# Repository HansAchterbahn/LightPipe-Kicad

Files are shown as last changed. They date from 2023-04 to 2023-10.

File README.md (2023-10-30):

# LightPipe - Main PCB (Kicad)

LightPipes are colorful lighting pipes that can be combined to create complex and interesting geometries. The LightPipe project is based on the easily addressable APA102 RGB LEDs. Each LED in a LightPipe geometry can be addressed individually.

The LightPipe project uses the PCB in this project in a slightly modified form as input and output PCB. On the input side, it simply accepts data from a 3.5 jack and power from an XT30 connector. On the output side, the data is output to the next LightPipe via the same jack and power is supplied via the same XT30 connector.

An additional 3.5 female connector is used to tunnel the data from the output PCB back to the input PCB. With this arrangement it is possible to realize a complete tree structure and therefore to create arbitrary geometries.

In this repository you will find the schematics and board layouts created in KiCad. You will also find a 3D model of the PCB.

*Fork me and have fun!*

LightPipe first Prototyep @ Neotopia Hackspace in Göttingen
**LightPipe - First Prototyep @ Neotopia Hackspace in Göttingen**

## PCB 3D view

Animated 3D STL model: [kibot/3d/model](kibot/3d/model)

__Top view__

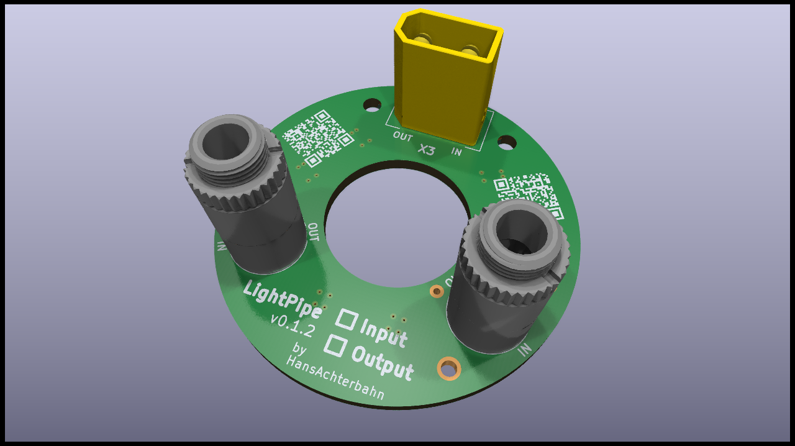
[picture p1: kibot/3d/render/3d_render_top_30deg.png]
Top view 30°


__Bottom view__

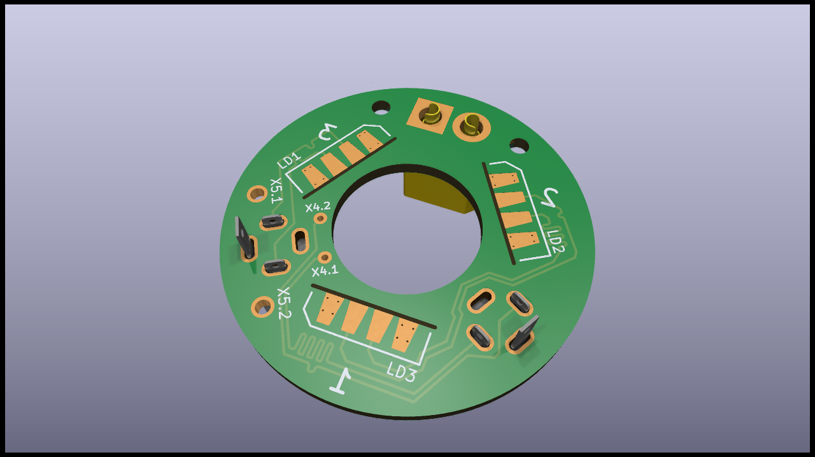
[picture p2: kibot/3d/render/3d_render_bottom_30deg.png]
Bottom view


## Schematic

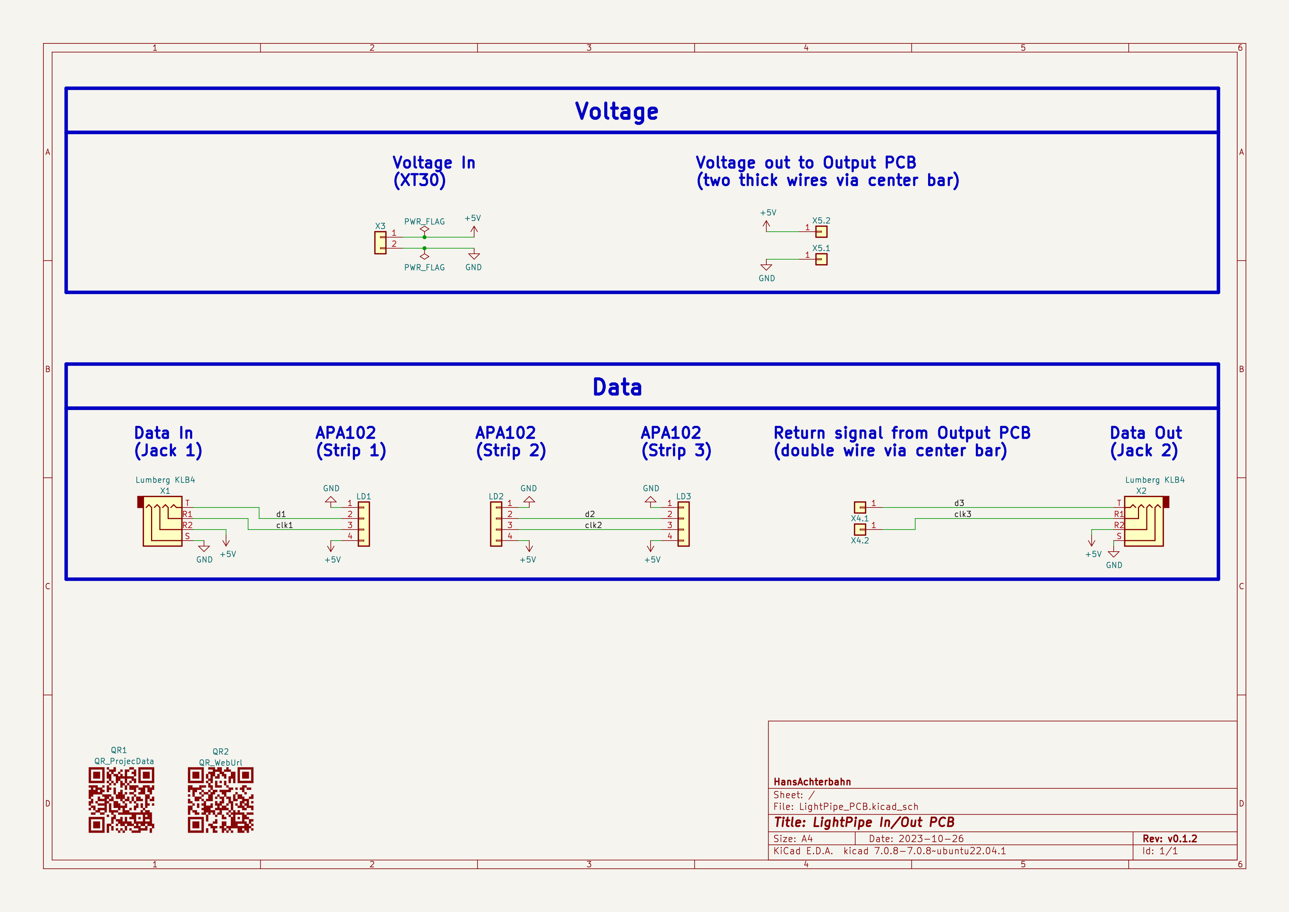
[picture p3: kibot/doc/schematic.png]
Schematic view


## Board

__Top view__

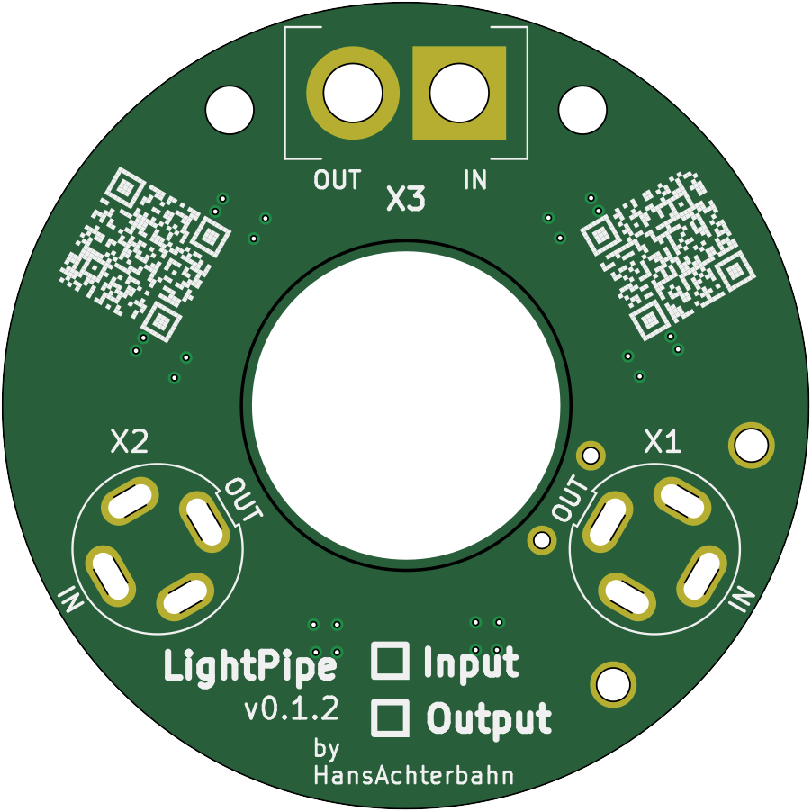
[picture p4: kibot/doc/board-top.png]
Top view


__Bottom view__

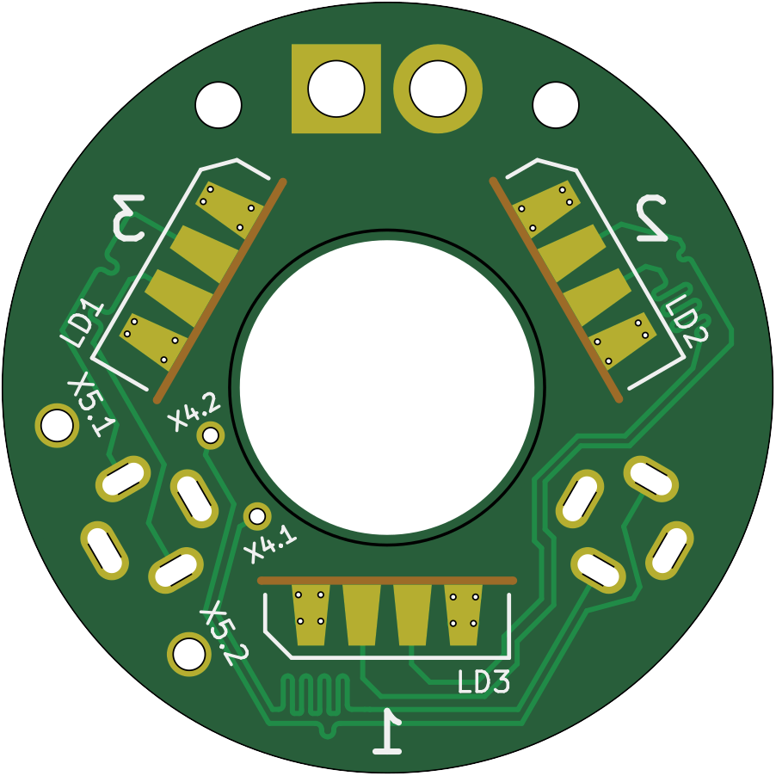
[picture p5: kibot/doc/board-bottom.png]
Bottom view


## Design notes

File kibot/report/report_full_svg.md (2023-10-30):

# PCB

Board size: 38.0x38.0 mm (1.5x1.5 inches)

- This is the size of the rectangle that contains the board
- Thickness: 1.6 mm (63 mils)
- Material: FR4
- Finish: None
- Layers: 4
- Copper thickness: 35 µm

Solder mask: TOP / BOTTOM

- Color: Green

Silk screen: TOP / BOTTOM

- Color: White

Stackup:

| Name | Type | Color | Thickness | Material | Epsilon_r | Loss tangent |
|---|---|---|---|---|---|---|
| F.SilkS | Top Silk Screen | | | | | |
| F.Paste | Top Solder Paste | | | | | |
| F.Mask | Top Solder Mask | | 10 | | | |
| F.Cu | copper | | 35 | | | |
| dielectric 1 | core | | 695 | FR4 | 4.5 | 0.020 |
| In1.Cu | copper | | 35 | | | |
| dielectric 2 | prepreg | | 50 | FR4 | 4.5 | 0.020 |
| In2.Cu | copper | | 35 | | | |
| dielectric 3 | core | | 695 | FR4 | 4.5 | 0.020 |
| B.Cu | copper | | 35 | | | |
| B.Mask | Bottom Solder Mask | | 10 | | | |
| B.Paste | Bottom Solder Paste  | | | | | |
| B.SilkS | Bottom Silk Screen | | | | | |

# Important sizes

Clearance: 0.2 mm (8 mils)

Track width: 0.25 mm (10 mils)

- By design rules: 0.2 mm (8 mils)

Drill: 0.3 mm (12 mils)

- Vias: 0.3 mm (12 mils) [Design: 0.3 mm (12 mils)]
- Pads: 0.8 mm (31 mils)
- The above values are real drill sizes, they add 0.1 mm (4 mils) to plated holes (PTH)

Via: 0.6/0.2 mm (24/8 mils)

- By design rules: 0.4/0.2 mm (16/8 mils)
- Micro via: yes [0.2/0.1 mm (8/4 mils)]
- Buried/blind via: yes
- Total: 24 (thru: 24 buried/blind: 0 micro: 0)

Outer Annular Ring: 0.15 mm (6 mils)

- By design rules: 0.15 mm (6 mils)

Eurocircuits class: 4D
- Using min drill 0.3 mm for an OAR of 0.15 mm

# General stats

Components count: (SMD/THT)

- Top: 0/3 (THT)
- Bottom: 3/2 (SMD + THT)

Defined tracks:

- 0.5 mm (20 mils)
- 0.75 mm (30 mils)
- 1.0 mm (39 mils)
- 1.5 mm (59 mils)
- 2.0 mm (79 mils)

Used tracks:

- 0.25 mm (10 mils) (114) defined: no

Defined vias:

- 0.6/0.2 mm (24/8 mils)

Used vias:

- 0.6/0.2 mm (24/8 mils) (Count: 24, Aspect: 2.7 A) defined: yes

Holes (excluding vias):

- 0.7 mm (28 mils) (2)
- 1.5 mm (59 mils) (2)
- 2.2 mm (87 mils) (2)
- 2.7 mm (106 mils) (2)

Oval holes:

- 1.0x2.2 mm (39x87 mils) (4)
- 1.0x2.4 mm (39x94 mils) (4)

Drill tools (including vias and computing adjusts and rounding):

- 0.3 mm (12 mils) (24)
- 0.8 mm (31 mils) (2)
- 1.1 mm (43 mils) (8)
- 1.6 mm (63 mils) (2)
- 2.2 mm (87 mils) (2)
- 2.8 mm (110 mils) (2)

# PCB Layers

PCB Top

PCB In1

PCB In2

PCB Bottom

PCB Assembly Top

PCB Assembly Bottom

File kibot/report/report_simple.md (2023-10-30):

PCB Specifications:
Size:

- 38.0x38.0 mm

Class: 4D

Track width: >= 0.25 mm

Insulation distance: >= 0.2 mm

Minimum drill size: >= 0.3 mm (finished metalized hole: 0.2 mm)

Minimum slot width: >= 1.0 mm

Ring collar: >= 0.15 mm

Stackup:

| Name | Type | Color | Thickness | Material | Epsilon_r | Loss tangent |
|---|---|---|---|---|---|---|
| F.SilkS | Top Silk Screen | | | | | |
| F.Paste | Top Solder Paste | | | | | |
| F.Mask | Top Solder Mask | | 10 | | | |
| F.Cu | copper | | 35 | | | |
| dielectric 1 | core | | 695 | FR4 | 4.5 | 0.020 |
| In1.Cu | copper | | 35 | | | |
| dielectric 2 | prepreg | | 50 | FR4 | 4.5 | 0.020 |
| In2.Cu | copper | | 35 | | | |
| dielectric 3 | core | | 695 | FR4 | 4.5 | 0.020 |
| B.Cu | copper | | 35 | | | |
| B.Mask | Bottom Solder Mask | | 10 | | | |
| B.Paste | Bottom Solder Paste  | | | | | |
| B.SilkS | Bottom Silk Screen | | | | | |

Materials:

- FR4, 1.6 mm
- None
- 4 layers
- 35 µm copper thickness

Solder mask:

- TOP / BOTTOM
- Green

Marking:

- TOP / BOTTOM screen printing
- Silk: White

Other markings:

- ROHS / UL / Date - Yes if available

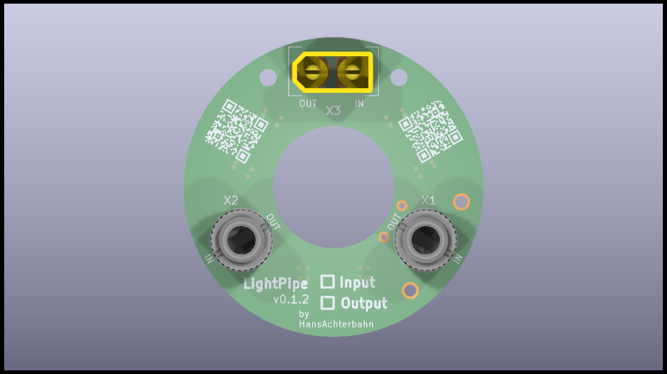
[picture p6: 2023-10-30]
kibot/3d/render/3d_render_top.png

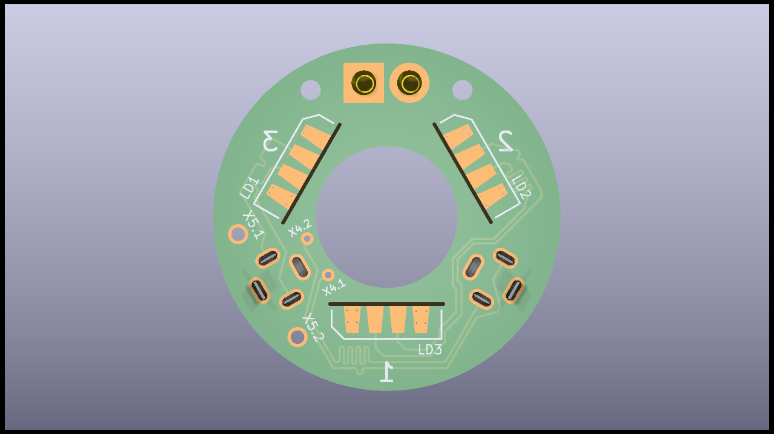
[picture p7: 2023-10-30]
kibot/3d/render/3d_render_bottom.png

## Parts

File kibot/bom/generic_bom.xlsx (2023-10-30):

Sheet: BoM
 |  | KiBot Bill of Materials
 |  | Schematic: | LightPipe_PCB | Component Groups: | 2
 |  | Variant: | default | Component Count: | 3 (0 SMD/ 3 THT)
 |  | Revision: | v0.1.2 | Fitted Components: | 3 (0 SMD/ 3 THT)
 |  | Date: | 2023-10-26 | Number of PCBs: | 1
 |  | KiCad Version: | 7.0.8-7.0.8~ubuntu22.04.1 | Total Components: | 3
Row | Description | Part | References | Value | Footprint | Quantity Per PCB | Status | Datasheet | MF | MFN | LCSC# | MF1 | MFN1 | qr_version | qr_size | qr_ecc | qr_mask | qr_text
1 | Audio Jack, 4 Poles (TRRS) | AudioJack4 | X1 X2 | Lumberg KLB4 | Lumberg-KLB-4-Jack-3_5-180deg-turnable | 2 |  | https://downloads.lumberg.com/datenblaetter/en/klb4.pdf | Lumberg | KLB4 |  | HUXUAN | PJ392
2 | Generic connector, single row, 01x02, script generated (kicad-library-utils/schlib/autogen/connector/) | Conn_01x02 | X3 | XT30 | XT30 | 1 |  | https://datasheet.lcsc.com/lcsc/2207151430_Changzhou-Amass-Elec-XT30UPB30-F-G--_C108769.pdf | Changzhou Amass Elec | XT30UPB30-F.G.* | C108769

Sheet: Colors
KiCad Fields (default)
Generated Fields
User Fields
Empty Fields

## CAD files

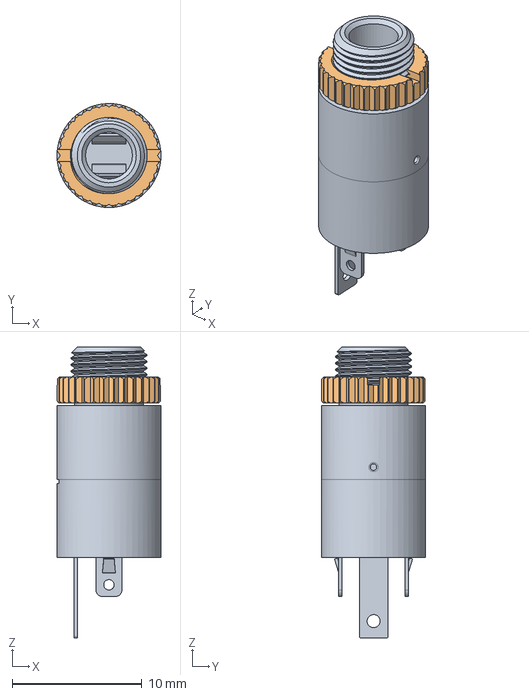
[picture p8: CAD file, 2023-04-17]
3D-Modells/Lumberg_KLB_4.stp
8.00 x 8.00 x 22.4 mm

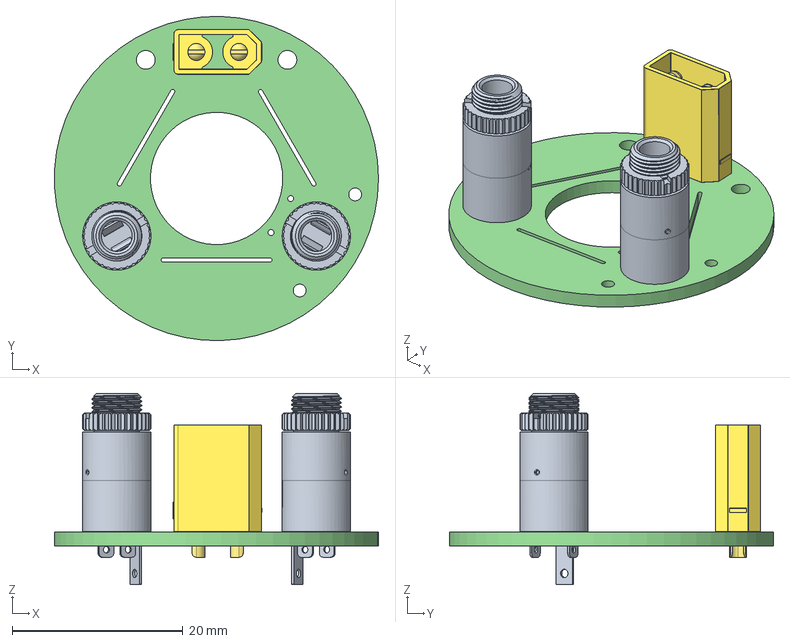
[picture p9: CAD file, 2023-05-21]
kibot/3d/model/LightPipe_PCB-3D-Model.step
38.0 x 38.0 x 22.4 mm
LightPipe_PCB PCB

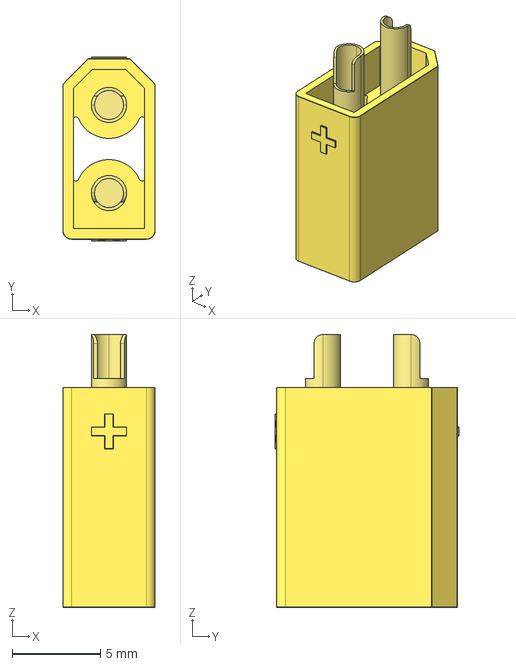
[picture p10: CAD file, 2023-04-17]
3D-Modells/XT30-male.stp
5.25 x 10.4 x 15.5 mm

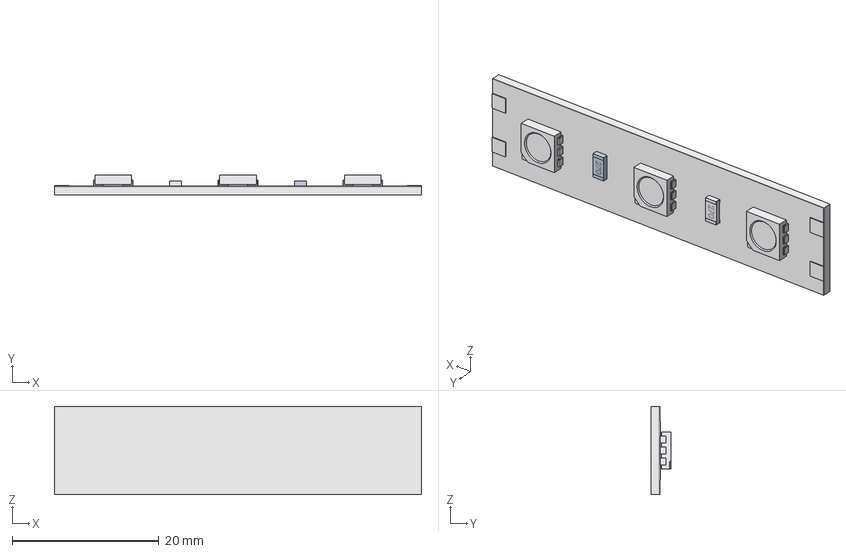
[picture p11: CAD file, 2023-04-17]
3D-Modells/LED-Strip-5050-2-Pole.stp
50.0 x 2.70 x 12.0 mm
stripPad
led5052 x 3
Resistor1206
Resistor1207

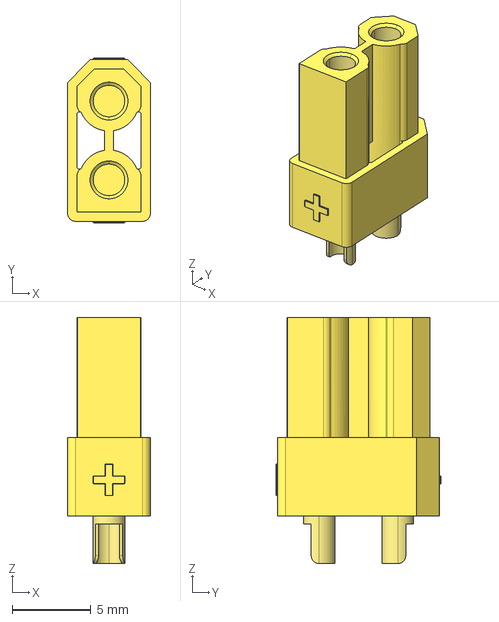
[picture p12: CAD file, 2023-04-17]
3D-Modells/XT30-female.stp
5.25 x 10.4 x 15.6 mm

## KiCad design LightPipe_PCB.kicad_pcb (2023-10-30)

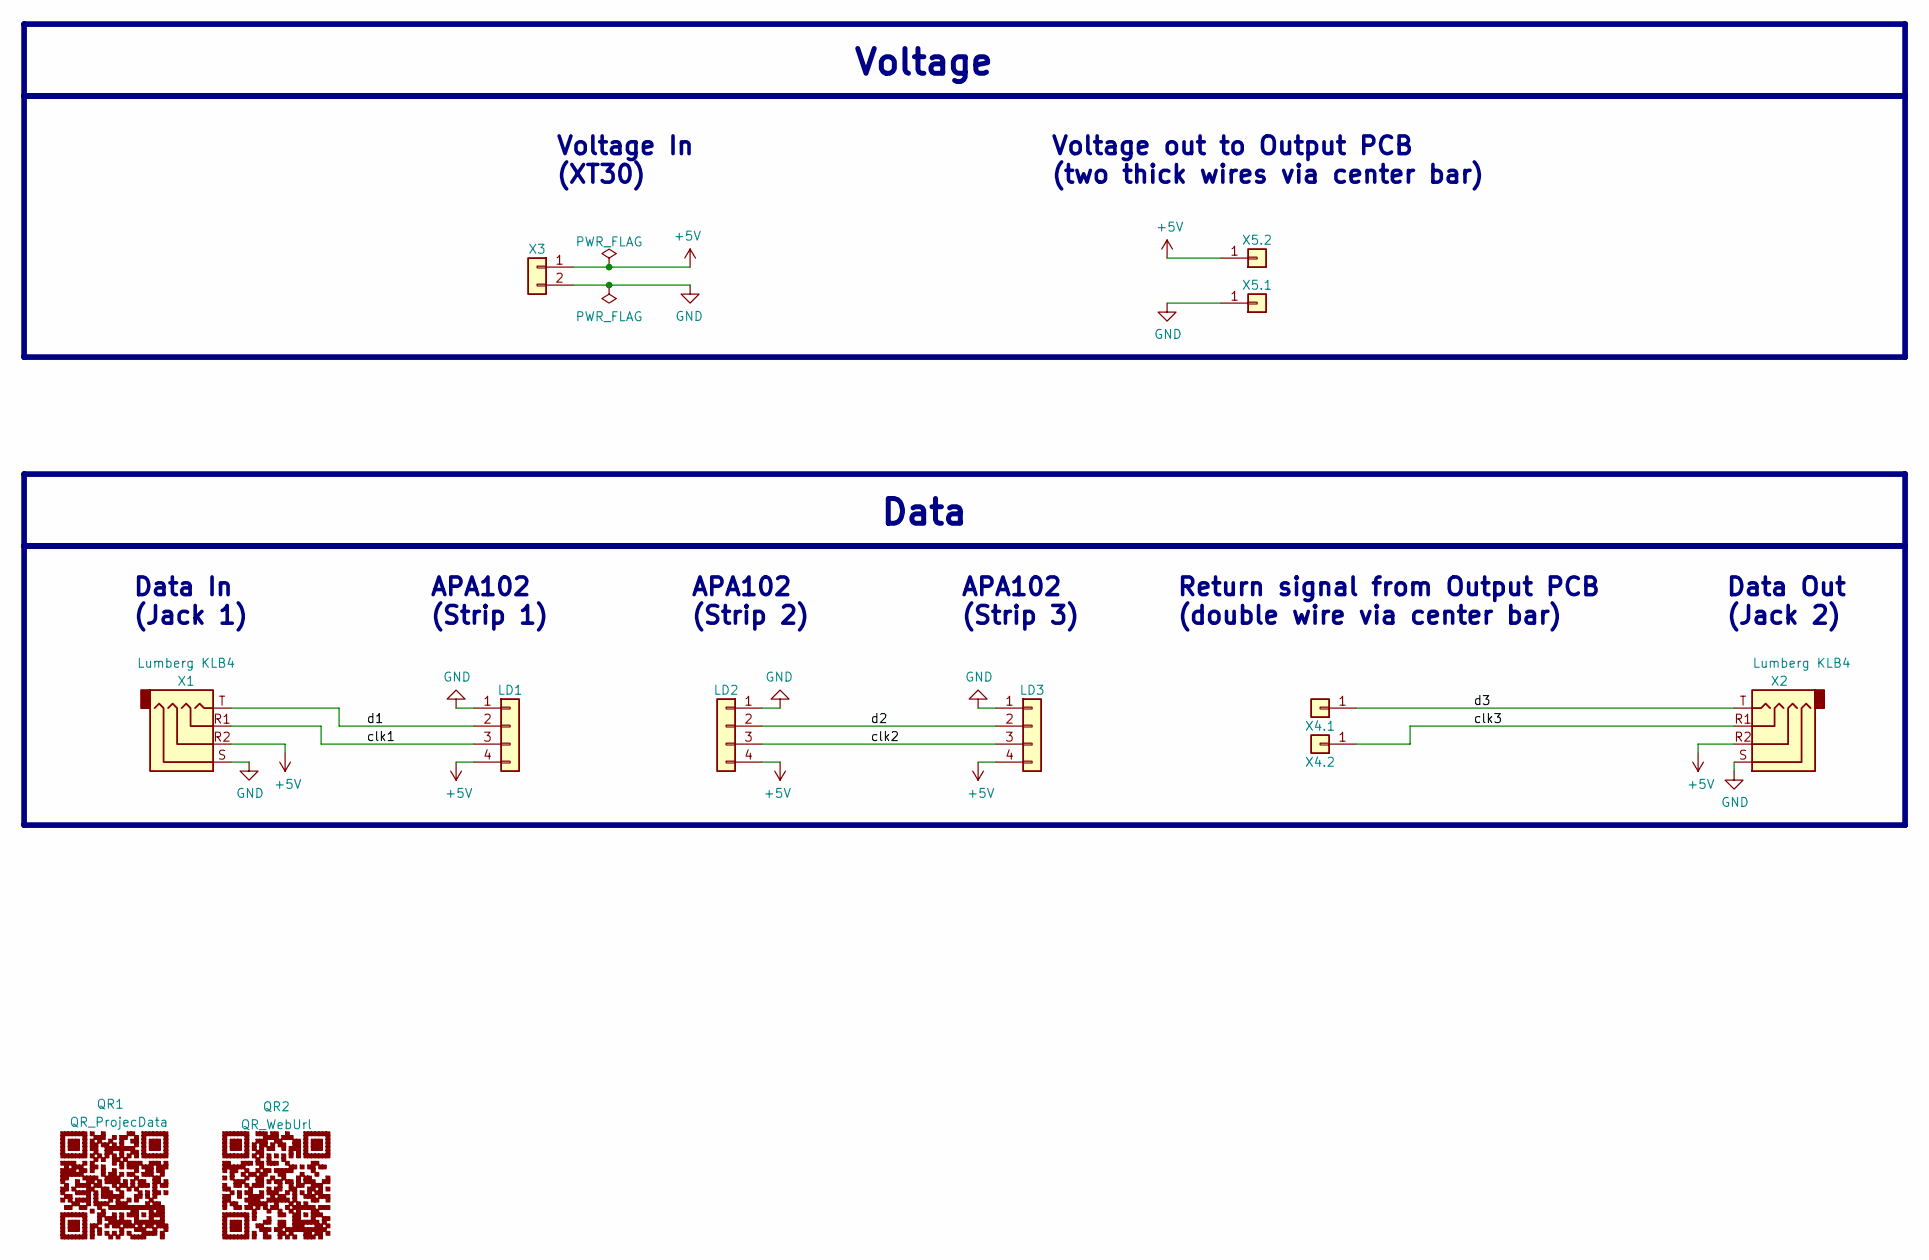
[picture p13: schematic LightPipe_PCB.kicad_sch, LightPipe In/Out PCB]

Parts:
LD1, LD3: APA102; APA102-Strip-Output
LD2: APA102; APA102-Strip-Input
QR1: QR_ProjecData
QR2: QR_WebUrl
X1, X2: Lumberg KLB4; Lumberg-KLB-4-Jack-3_5-180deg-turnable
X3: XT30; LCSC# C108769
X4.1, X4.2: Cable-0.7mm; Solder-Pad-THT-0.7mm
X5.1, X5.2: Cable-1.5mm; Solder-Pad-THT-1.5mm

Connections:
+5V: LD1.4, LD2.4, LD3.4, X1.R2, X2.R2, X3.1, X5.2.1
/clk1: LD1.3, X1.R1
/clk2: LD2.3, LD3.3
/clk3: X2.R1, X4.2.1
/d1: LD1.2, X1.T
/d2: LD2.2, LD3.2
/d3: X2.T, X4.1.1
GND: LD1.1, LD2.1, LD3.1, X1.S, X2.S, X3.2, X5.1.1

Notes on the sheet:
Data Out (Jack 2)
APA102 (Strip 1)
APA102 (Strip 3)
Data
Return signal from Output PCB (double wire via center bar)
Data In (Jack 1)
APA102 (Strip 2)
Voltage out to Output PCB (two thick wires via center bar)
Voltage
Voltage In (XT30)

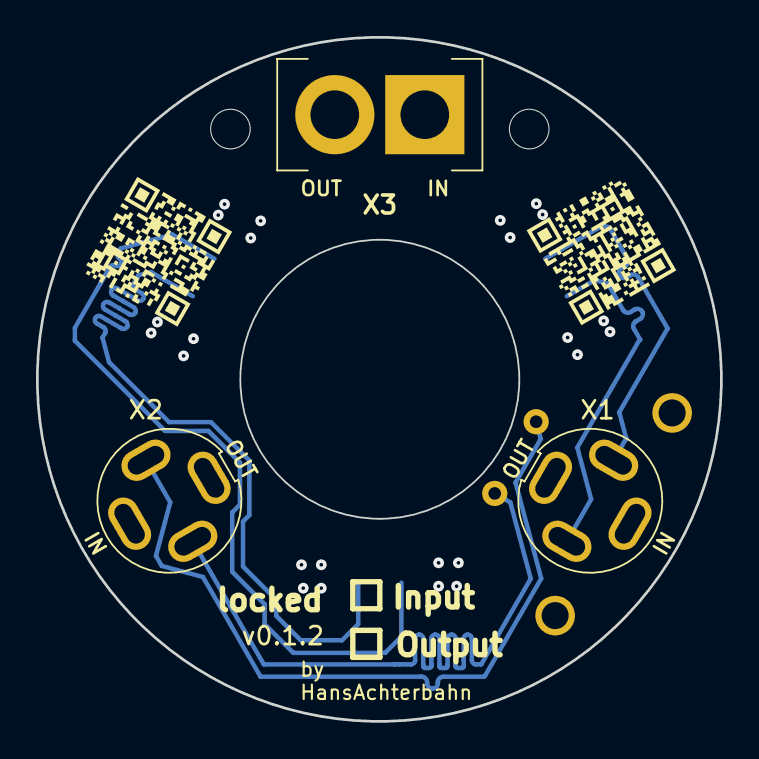
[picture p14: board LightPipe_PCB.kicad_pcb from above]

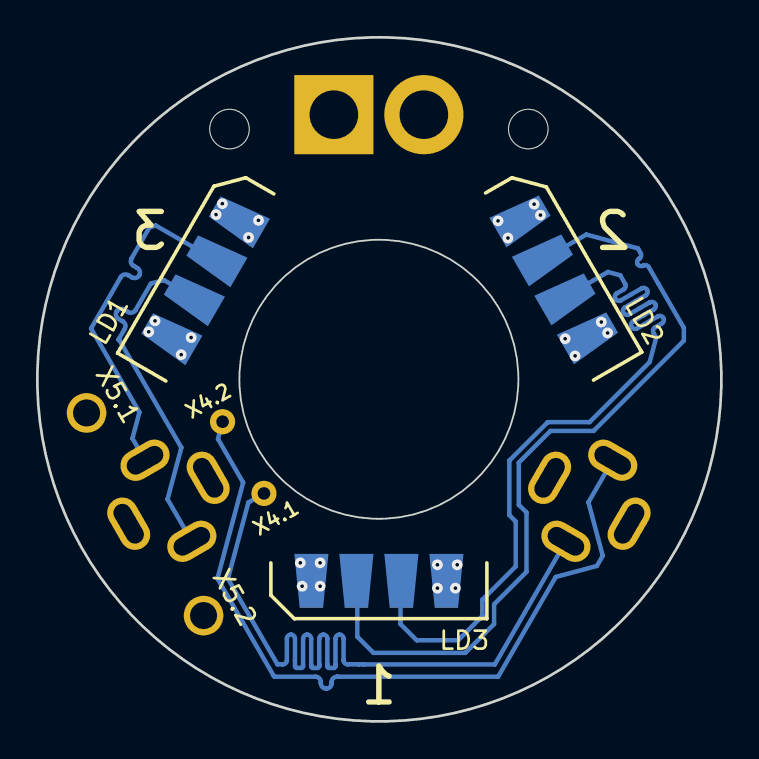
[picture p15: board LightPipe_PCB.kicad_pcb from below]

Board: 4 copper layers, 38.0 x 38.0 mm, 14 parts (7 on the bottom side), 8 nets.

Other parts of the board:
M1, M2: 2.2mm_M2; MountingHole_2.2mm_M2

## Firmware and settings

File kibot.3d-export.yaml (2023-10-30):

# This is a working example.
# For a more complete reference use `--example`
kibot:
  version: 1

preflight:
  # [boolean=false] Zones are filled before doing any operation involving PCB layers
  check_zone_fills: true
  # [boolean=false] Option for `run_drc`. Ignores the unconnected nets. Useful if you didn't finish the routing
  ignore_unconnected: false
  # [boolean=false] Runs the DRC (Distance Rules Check). To ensure we have a valid PCB
  run_drc: false
  # [boolean=false] Runs the ERC (Electrical Rules Check). To ensure the schematic is electrically correct
  run_erc: false
  # [boolean=false] Update the XML version of the BoM (Bill of Materials).
       # To ensure our generated BoM is up to date.
       # Note that this isn't needed when using the internal BoM generator (`bom`)
  update_xml: false

global:
  filters:
  - number: 1007
  - number: 1015
  - number: 58

filters:
- name: only_jlc_parts
  comment: Only parts with JLC (LCSC) code
  type: generic
  include_only:
  - column: LCSC#
    regex: ^C\d+

variants:
- name: place_holder
  comment: Just a place holder for pre_transform filters
  type: kicost
  pre_transform:
  - _kicost_rename
  - _rot_footprint

outputs:

################################################################################
# PCB Draw (2D Board Renderer)
################################################################################
- name: basic_pcbdraw_svg_jlcpcb_green_enig_top
  comment: PCB 2D render in SVG format, using jlcpcb-green-enig style
  type: pcbdraw
  dir: kibot/doc
  options:
    style: jlcpcb-green-enig
    format: png
    dpi: 600
    output: 'board-top.%x'
- name: basic_pcbdraw_svg_jlcpcb_green_enig_bottom
  comment: PCB 2D render in SVG format, using jlcpcb-green-enig style
  type: pcbdraw
  dir: kibot/doc
  options:
    style: jlcpcb-green-enig
    format: png
    dpi: 600
    bottom: true
    output: 'board-bottom.%x'
    show_components: 'all'


################################################################################
# 3D Model
################################################################################

# # 3D STEP model creation
# - name: basic_step
#   comment: 3D model in STEP format
#   type: step
#   dir: kibot/3d/model
#   options:
#     output: '%f-3D-Model.%x'

# 3D Renderer
- name: basic_render_3d_top
  comment: 3D view from top
  type: render_3d
  dir: kibot/3d/render
  options:
    output: '3d_render_top.%x'
    ray_tracing: true
    orthographic: true
    zoom: 3
    height:  720 #1440
    width:  1280 #2560
- name: basic_render_3d_top_30deg
  comment: 3D view from top 30 degrees
  type: render_3d
  dir: kibot/3d/render
  output_id: 30deg
  options:
    output: '3d_render_top_30deg.%x'
    ray_tracing: true
    rotate_x: 3
    rotate_z: 2
    zoom: 3
    height:  720 #1440
    width:  1280 #2560
- name: basic_render_3d_bottom
  comment: 3D view from bottom
  type: render_3d
  dir: kibot/3d/render
  options:
    output: '3d_render_bottom.%x'
    ray_tracing: true
    orthographic: true
    view: bottom
    zoom: 3
    height:  720 #1440
    width:  1280 #2560
- name: basic_render_3d_bottom_30deg
  comment: 3D view from bottom 30 degrees
  type: render_3d
  dir: kibot/3d/render
  output_id: 30deg
  options:
    output: '3d_render_bottom_30deg.%x'
    ray_tracing: true
    rotate_x: 3
    rotate_z: -2
    view: bottom
    zoom: 3
    height:  720 #1440
    width:  1280 #2560

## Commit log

2020-10-24 First schematic draft
    [LightPipe.kicad_pcb, LightPipe.sch]
2021-08-06 first PCB draft
    [LED-Strip-5050-2-Pole.stp, LightPipe.kicad_pcb, Lumberg_KLB_4.stp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]
2023-01-01 PCB looks quite good
    [LightPipe.kicad_pcb, LightPipe_Out_PCB.kicad_pcb, LightPipe_Out_PCB.kicad_sch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]
2023-01-01 changed position of some silkscreen names
    [LightPipe_Out_PCB.kicad_pcb]
2023-01-12 [PCB] New Design features to use the PCB as In- and Out-PCB
    [LightPipe_Out_PCB.kicad_pcb, LightPipe_Out_PCB.kicad_sch]
2023-01-16 Changed designators from J? to X? and LD? | Improved Footprints
    [LightPipe_Out_PCB.kicad_pcb, LightPipe_Out_PCB.kicad_sch]
2023-01-28 [PCB] Improved footprints | optimized footprint locations | optimized wires
    [LightPipe_Out_PCB.kicad_pcb, LightPipe_Out_PCB.kicad_sch]
2023-01-28 [clean] removed old schematic file type
    [LightPipe_Out_PCB.sch]
2023-01-28 [doc] Create KiBot export and a basic documentation in README.md
    [LightPipe_Out_PCB-3D-Model.step, LightPipe_Out_PCB.kicad_pcb, generic_bom.xlsx]
2023-01-28 [QR] Added QR-Code to schematic | defined QR-Code on Board to be not on schematic
    [LightPipe_Out_PCB.kicad_pcb, LightPipe_Out_PCB.kicad_sch]
2023-04-07 [pcb] Optimized X1 and X2 positon
    [LightPipe_Out_PCB.kicad_pcb, LightPipe_Out_PCB.kicad_sch]
2023-04-07 [clean] Renamed project to have a generic name for input and output pcb
    [LightPipe_PCB.kicad_pcb, LightPipe_PCB.kicad_sch]
2023-04-07 [clean] Optimized schematic to be easy readable as input PCB | changed 3D bodys in PCB to Input PCB positions | update date, company, project name and QR-code in schematic and board
    [LightPipe_PCB.kicad_pcb, LightPipe_PCB.kicad_sch]
2023-04-10 [mechanical constrains] increased inner board diameter | reduced outer board diameter | added PCB name, version and creator to silkscreen
    [LightPipe_PCB.kicad_pcb]
2023-04-10 [kibot] Executed Kibot script to generate documentation, manufacturing and assembly data
    [LightPipe_PCB-3D-Model.step, generic_bom.xlsx]
2023-04-12 [DRC] Solved DRC errors
    [LightPipe_PCB.kicad_pcb, LightPipe_PCB.kicad_sch]
2023-04-12 [kibot] Improved Settings: Inner layer in Gerber export were missing | reduced image size of 3d rendered PCB
    [LightPipe_Out_PCB-3D-Model.step, LightPipe_PCB-3D-Model.step, generic_bom.xlsx]
2023-04-28 [clean] improved schematic and pcb to be easier to read in Input-Mode
    [LightPipe_PCB.kicad_pcb, LightPipe_PCB.kicad_sch]
2023-05-04 [clean] improved schematic and pcb to be easier to read in Input-Mode 2
    [LightPipe_PCB.kicad_pcb, LightPipe_PCB.kicad_sch]
2023-05-06 [PCB] Update footprint APA102 → Reduced the size of the slit in the PCB
    [LightPipe_PCB.kicad_pcb]
2023-05-21 [PCB] Fixed Fab layers | added attributes to components
    [LightPipe_PCB.kicad_pcb, LightPipe_PCB.kicad_sch]
2023-05-21 [Kibot] Splited basic-export in to basic-export and 3d-export → better performance for basic-export
2023-05-21 [Kibot] Run job 'basic-export' and '3d-export'
    [LightPipe_PCB-3D-Model.step, generic_bom.xlsx]
2023-10-18 [WIP] Optimize PCB for more common LED-Strip (GND, D, CLK, 5V)
    [LightPipe_PCB.kicad_pcb, LightPipe_PCB.kicad_sch]
2023-10-18 Optimize PCB for more common LED-Strip (GND, D, CLK, 5V) → It could be a good idea to change X4.1, X4.2, X5.1 and X5.2 to a standard footprint. There is always trouble with this custom footprints.
    [LightPipe_PCB.kicad_pcb, LightPipe_PCB.kicad_sch]
2023-10-19 Try to run KiBot - but it does not work well with KiCad 7.0 → Downgrade to KiCad 6.0?
    [LightPipe_PCB--NPTH_map.gbr, LightPipe_PCB--PTH_map.gbr, LightPipe_PCB-B_Cu.gbl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]
2023-10-26 Optimized schematic and PCB by checking Gerber Data
    [LightPipe_PCB.kicad_pcb, LightPipe_PCB.kicad_sch]
2023-10-26 Optimized KiBot script to make it work as good as possible with KiCad 7.0
    [LightPipe_PCB--NPTH_map.gbr, LightPipe_PCB--PTH_map.gbr, LightPipe_PCB-B_Cu.gbl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]
2023-10-30 [PCB] Changed Layer In1 with In2 + Kibot Export
    [LightPipe_PCB--NPTH_map.gbr, LightPipe_PCB--PTH_map.gbr, LightPipe_PCB-B_Cu.gbl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]
